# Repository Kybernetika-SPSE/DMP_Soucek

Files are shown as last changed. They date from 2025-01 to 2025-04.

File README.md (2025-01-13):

## Cíl práce
Cílem maturitní práce je navrhnout a vytvořit zařízení pro přesné měření času na závodní dráze. Součástí systému bude displej, který umožní nejen ovládání celé dráhy, ale také bude zobrazovat aktuální čas měřený během závodu. Zařízení by mělo zajistit jednoduché uživatelské rozhraní a spolehlivou funkčnost, aby bylo vhodné pro závodní podmínky.

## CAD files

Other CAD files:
Přílohy/Příloha II. - 3D Modely/Krabicka_dolni.ipt
Přílohy/Příloha II. - 3D Modely/Krabička_horni.ipt
Přílohy/Příloha II. - 3D Modely/Sestava1.iam
Přílohy/Příloha II. - 3D Modely/Tlacitko.ipt
Přílohy/Příloha II. - 3D Modely/laser_krabicka2.ipt
Přílohy/Příloha II. - 3D Modely/nožička.ipt
Přílohy/Příloha II. - 3D Modely/senzor_obal.ipt

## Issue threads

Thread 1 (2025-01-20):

Ahoj Jirko, podíváš se mi prosím na to PCB, děkuji mockrát 🙏

jakubsoucek, 2025-01-20:
odkaz: [PCB](https://github.com/Kybernetika-SPSE/DMP_Soucek/tree/3d0ee29cd1a2d0d2b6c08e4d55e5cf3c0b7b84b3/PCB)

bublinak, 2025-02-01:
Dělič napětí pro baterii 1:3 ok, ale 1M:3M? Bojím se o stabilitu a vstupní impedanci toho ESPčka. Šel bych raději max. do 100k:330k

bublinak, 2025-02-01:
Osazení si budeš dělat hádám sám..?

bublinak, 2025-02-01:
Varování: používáš vestavěný 3,3V stabilizátor na ESP. Není zrovna z nejvýkonnějších. Raději bych viděl něco externího pro ty lasery apod. A nebo - protože většina potřebuje 4,5V a více, což ti vestavěná LiPolka nedá, tak je napoj rovnou na baterii nebo na 5V a na vstup dat ze senzoru dej 1:2 dělič pro ochranu toho ESP (třeba 10k:22k). Mělo by to fungovat dobře.

bublinak, 2025-02-01:
Bacha - nemáš propojenou jednu zem. Přenastav v zóně vylité mědi izol. mezeru a tepl. mezeru na 0,25. Šířku tepl. profilu nech na 0,5
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

bublinak, 2025-02-01:
Nemáš definované vel. prokovů. Default je 0,6 s dírou 0,3. To je minimum co ti JLC vyrobí, raději bych zvětšil na 0,8:0,4 třeba. Ale mělo by to být v pohodě.

bublinak, 2025-02-01:
Zbytek OK

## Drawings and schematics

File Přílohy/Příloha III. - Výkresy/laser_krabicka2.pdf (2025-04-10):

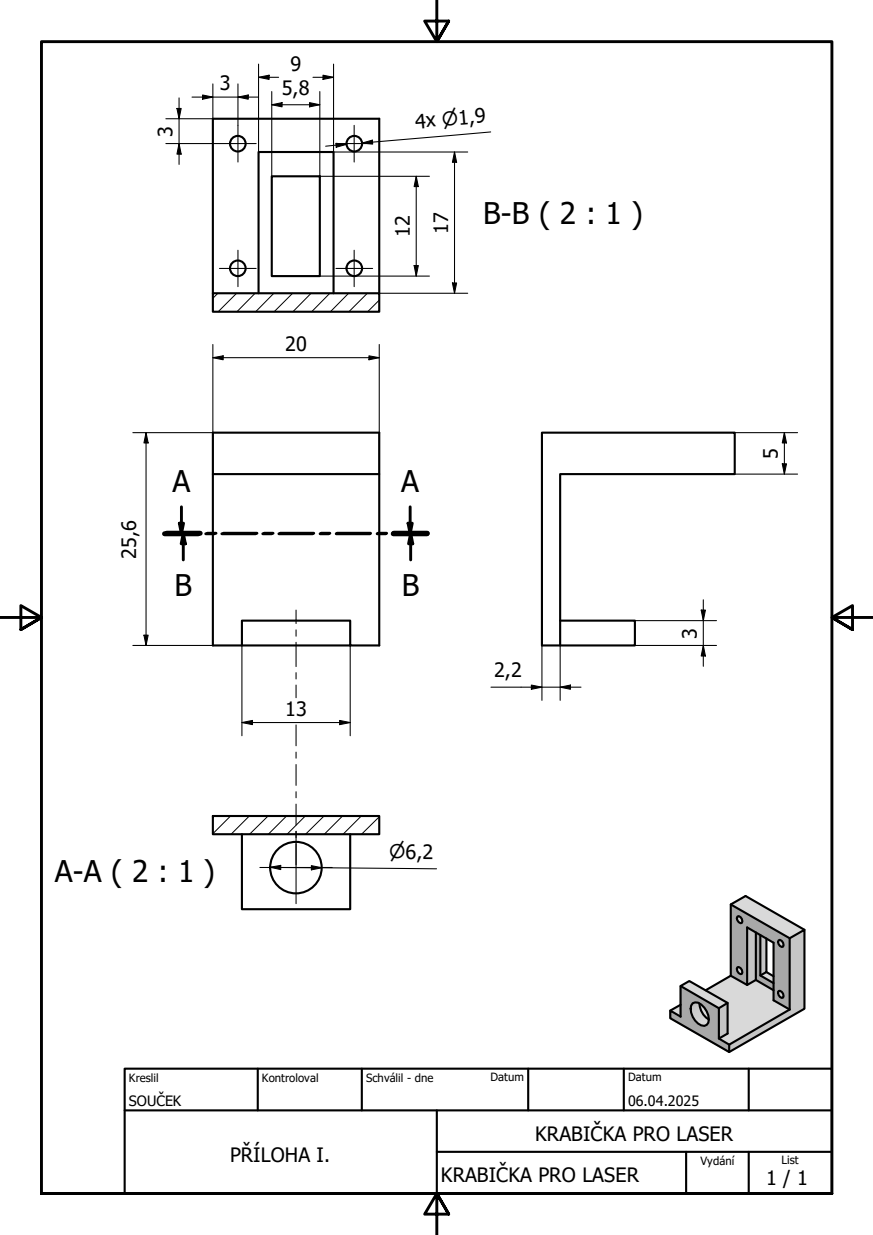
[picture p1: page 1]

Kreslil SOUČEK | Kontroloval | Schválil - dne Datum | Datum 06.04.2025

PŘÍLOHA I. | KRABIČKA PRO LASER

KRABIČKA PRO LASER | Vydání | List 1 / 1

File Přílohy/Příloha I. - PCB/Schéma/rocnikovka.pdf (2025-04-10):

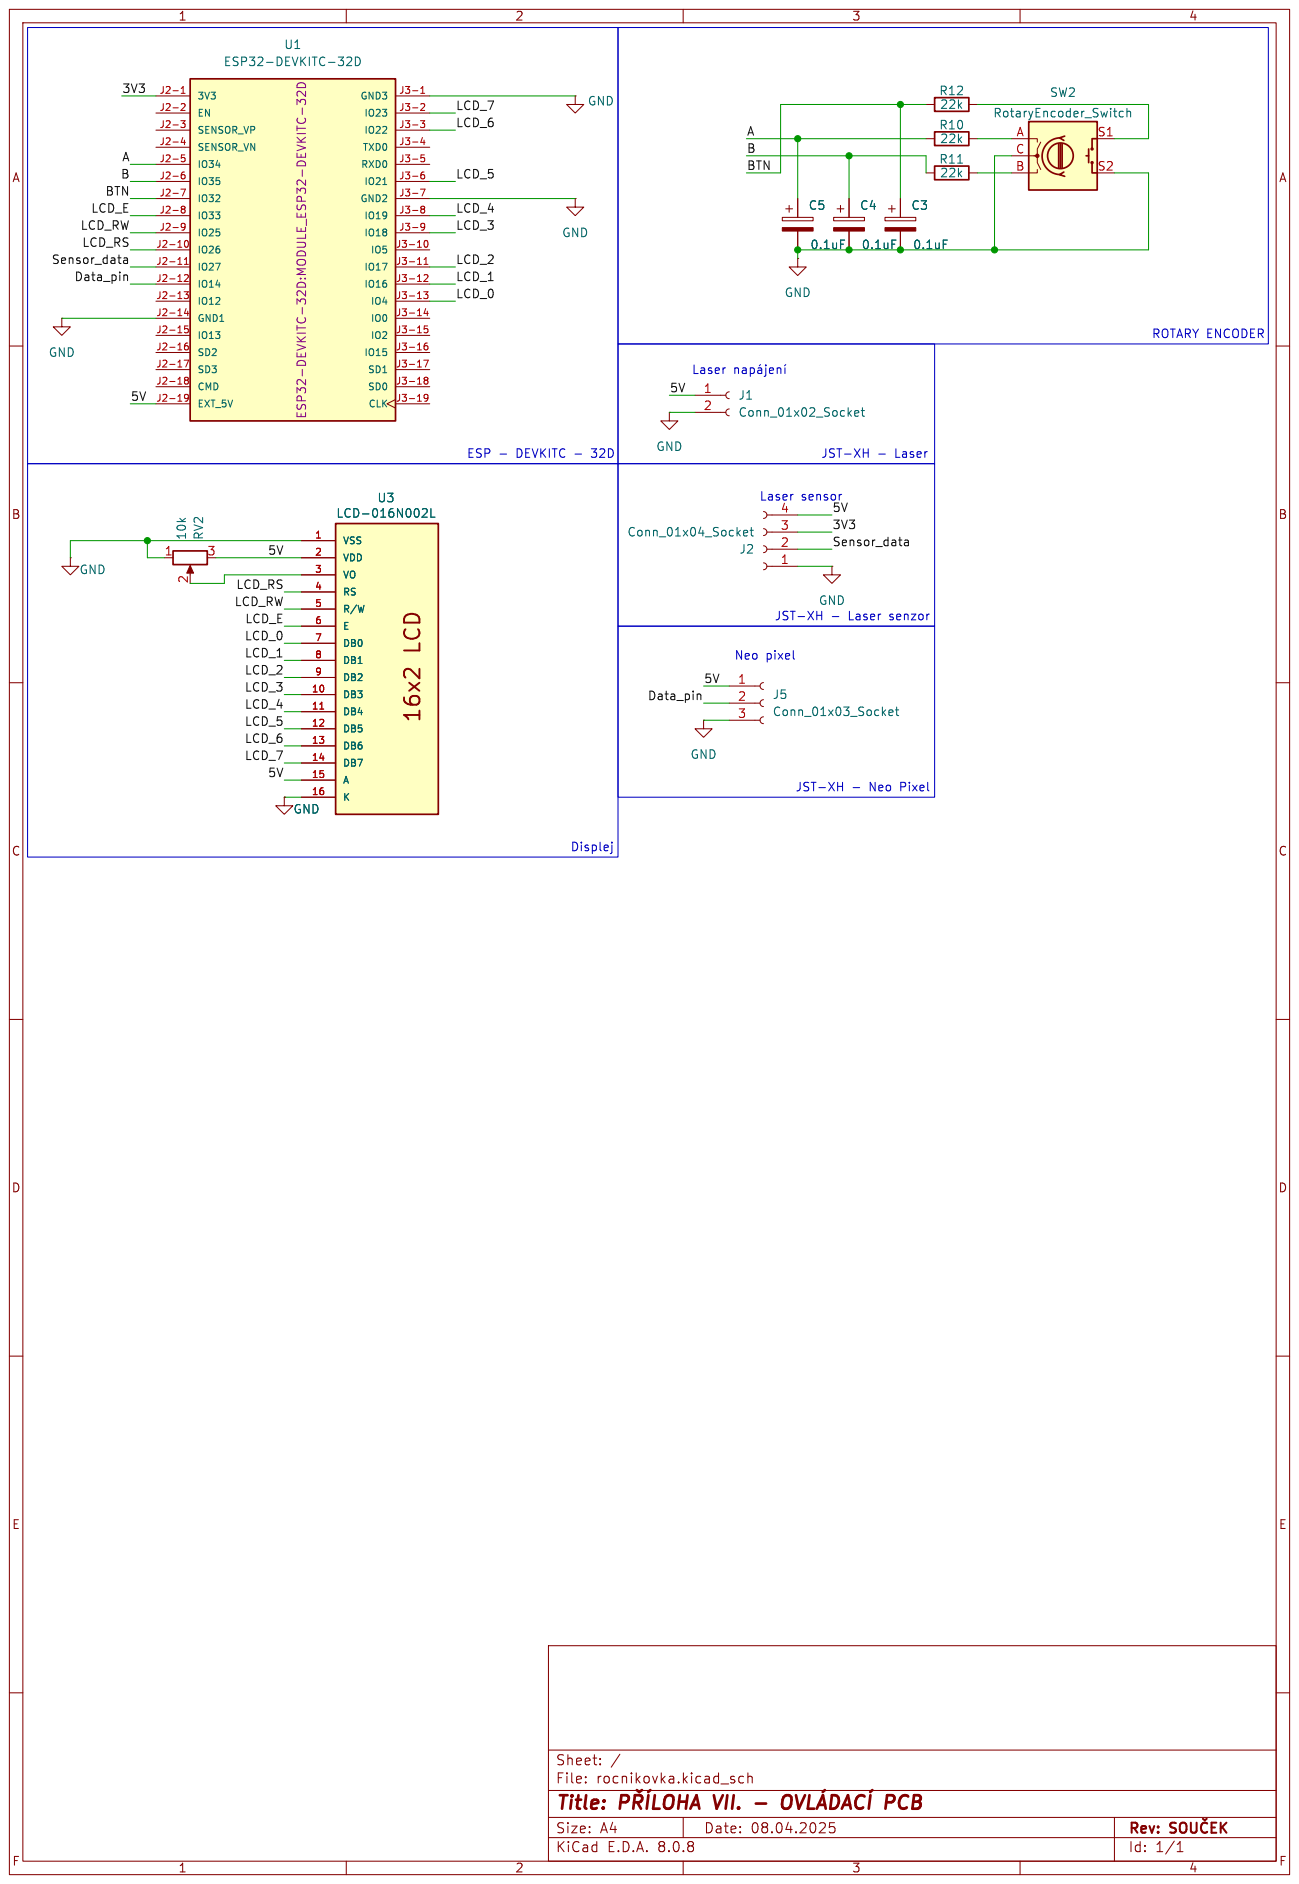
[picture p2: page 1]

Laser þÿnapájení JST-XH - Laser JST-XH - Neo Pixel C3
LCD_3

File: rocnikovka.kicad_sch Sheet: /
Id: 1/1 Title: þÿPXÍLOHA VII. - þÿOVLÁDACÍ PCB

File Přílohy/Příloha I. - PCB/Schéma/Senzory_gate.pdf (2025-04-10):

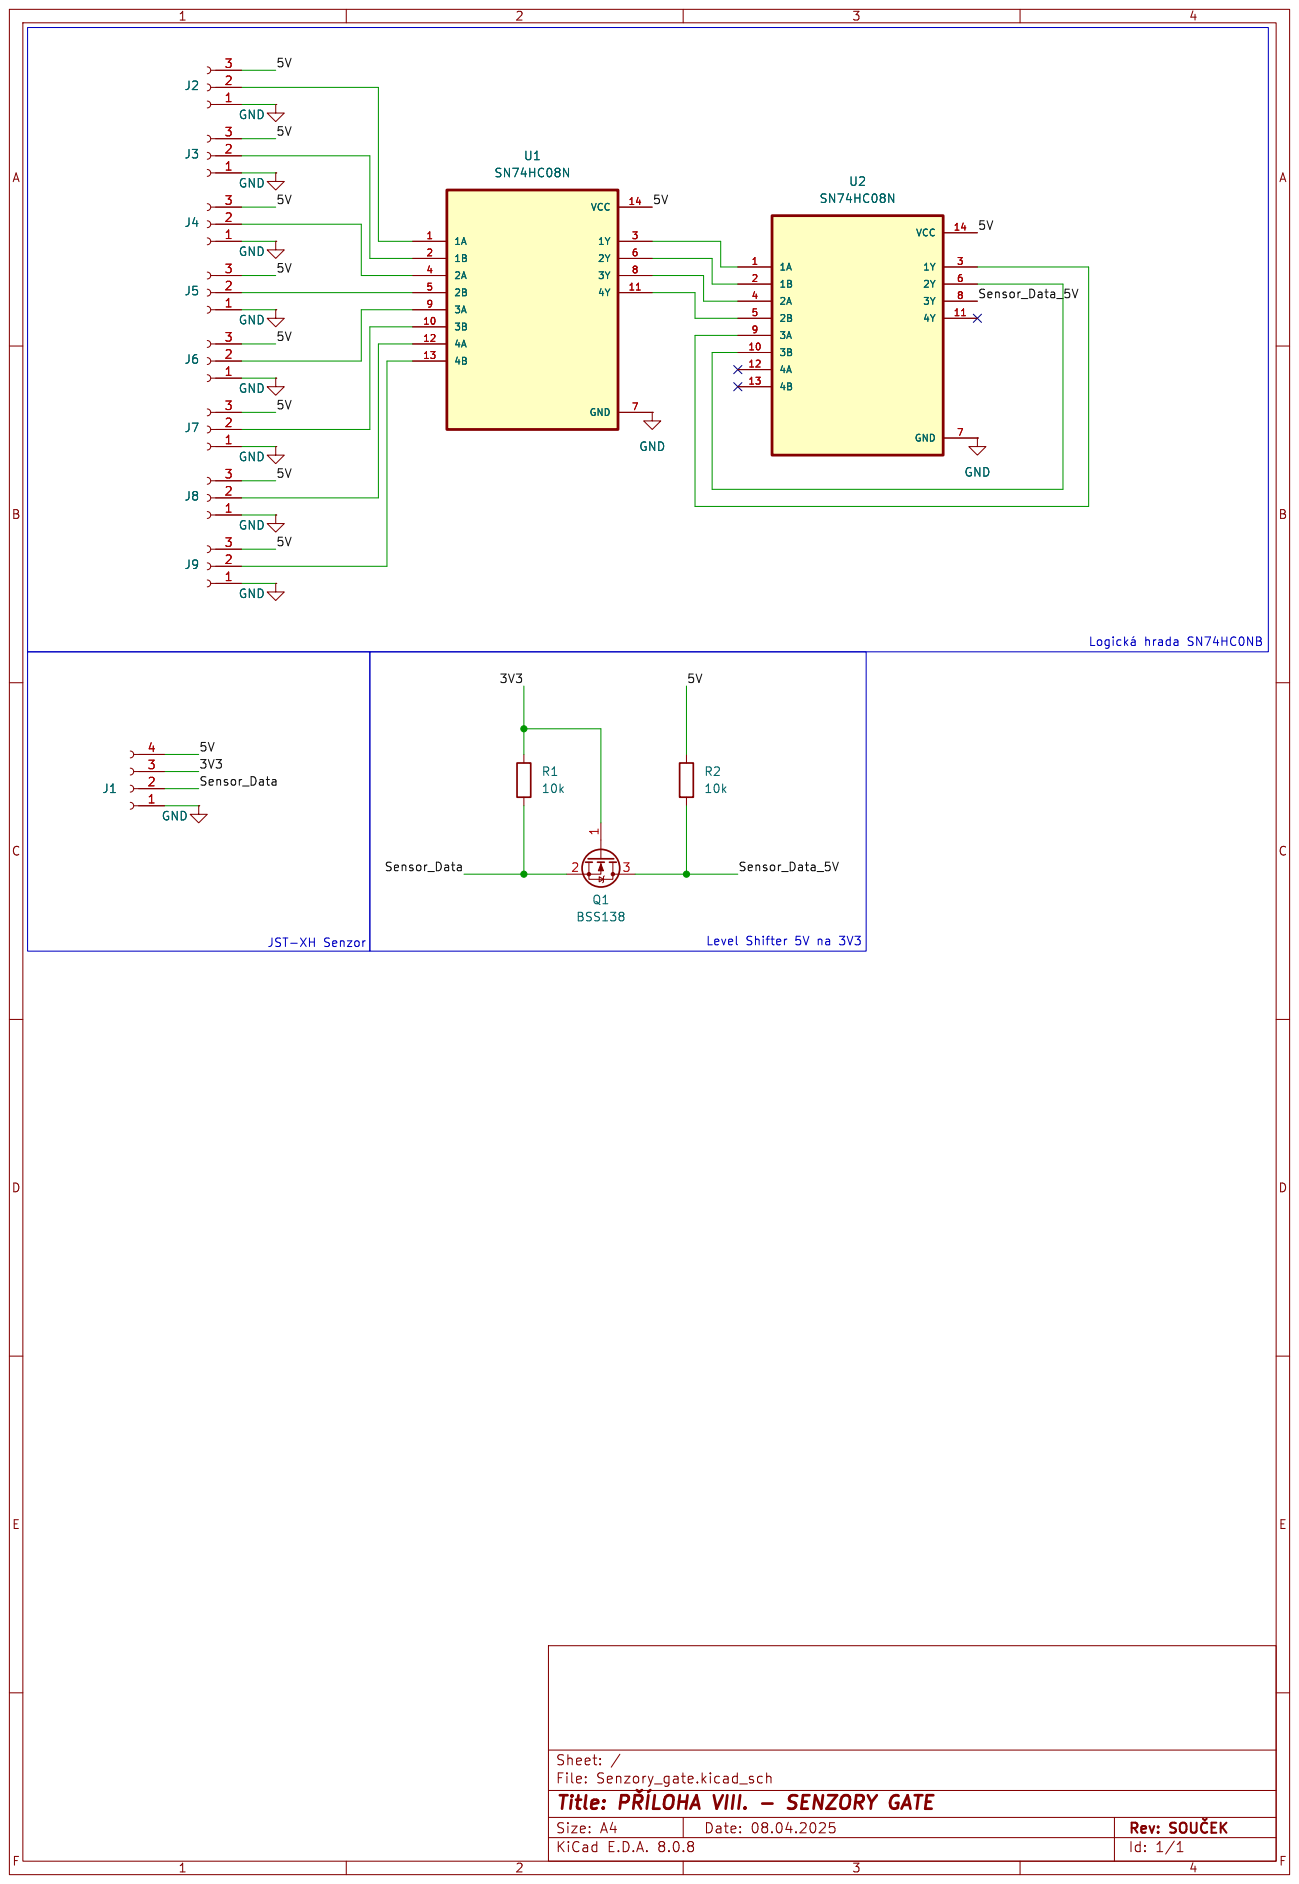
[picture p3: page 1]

File: Senzory_gate.kicad_sch Sheet: /
Id: 1/1 Title: þÿPXÍLOHA VIII. - SENZORY GATE

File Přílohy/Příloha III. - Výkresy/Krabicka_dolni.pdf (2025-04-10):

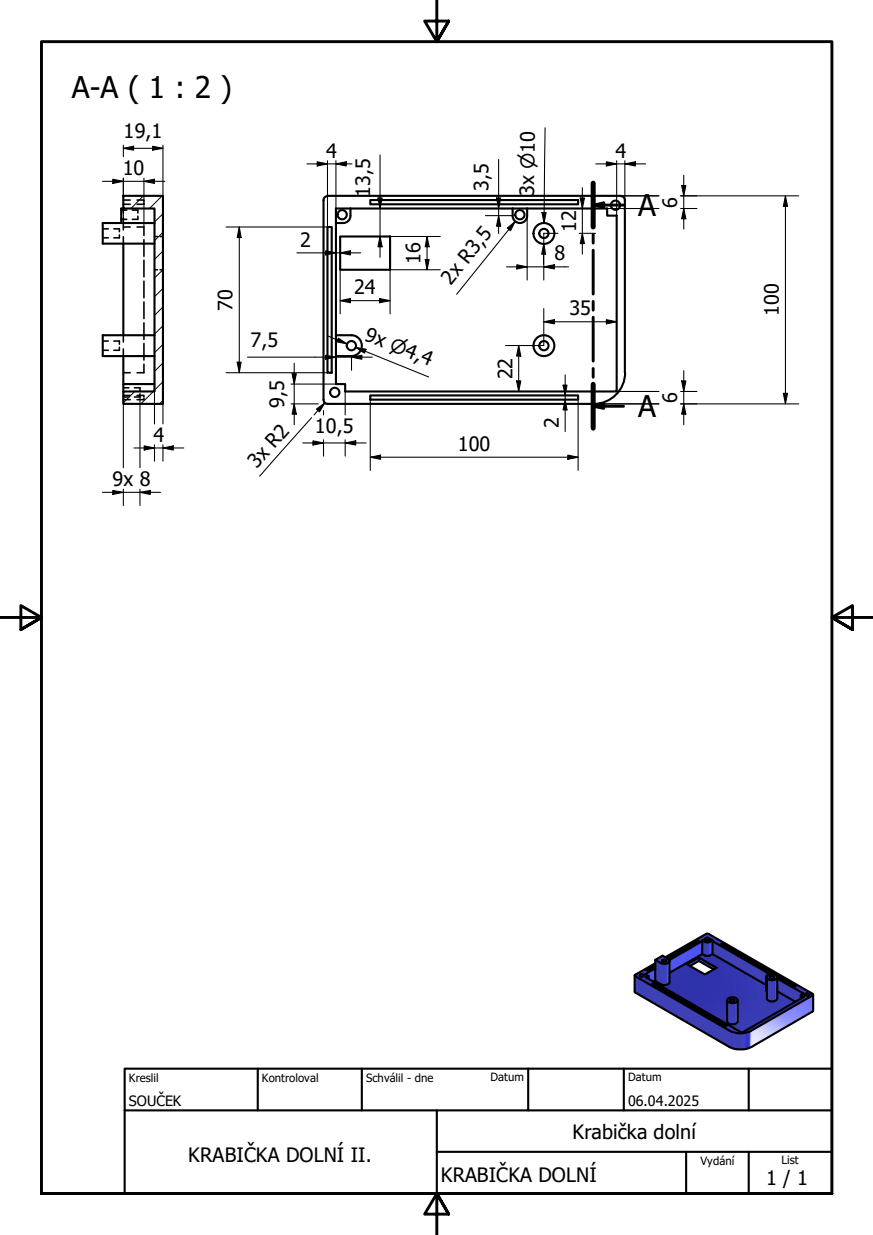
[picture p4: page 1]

Kreslil SOUČEK | Kontroloval | Schválil - dne Datum | Datum 06.04.2025

KRABIČKA DOLNÍ II. | Krabička dolní

KRABIČKA DOLNÍ | Vydání | List 1 / 1

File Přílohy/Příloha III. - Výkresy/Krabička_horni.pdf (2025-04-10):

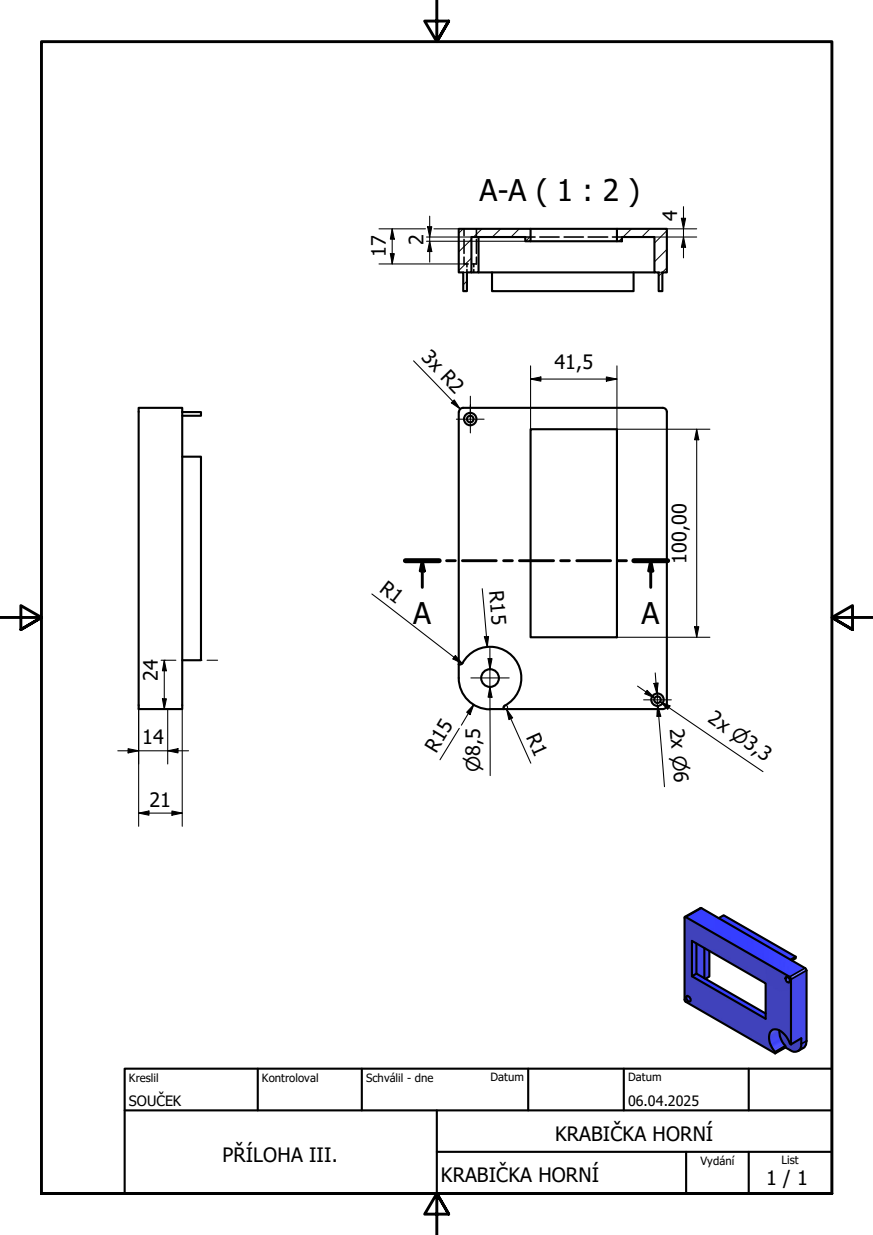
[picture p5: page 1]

Kreslil SOUČEK | Kontroloval | Schválil - dne Datum | Datum 06.04.2025

PŘÍLOHA III. | KRABIČKA HORNÍ

KRABIČKA HORNÍ | Vydání | List 1 / 1

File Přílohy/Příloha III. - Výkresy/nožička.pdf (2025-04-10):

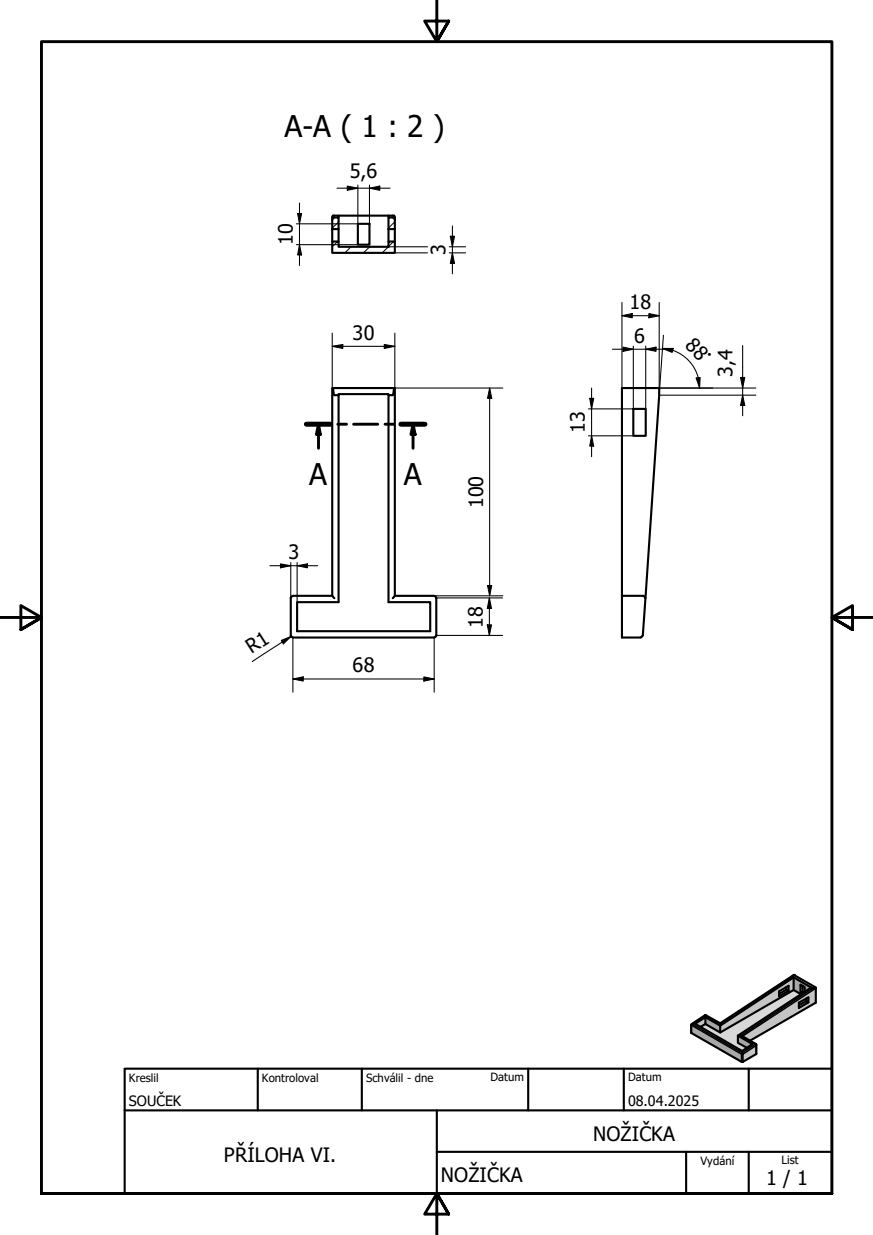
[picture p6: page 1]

Kreslil SOUČEK | Kontroloval | Schválil - dne Datum | Datum 08.04.2025

PŘÍLOHA VI. | NOŽIČKA

NOŽIČKA | Vydání | List 1 / 1

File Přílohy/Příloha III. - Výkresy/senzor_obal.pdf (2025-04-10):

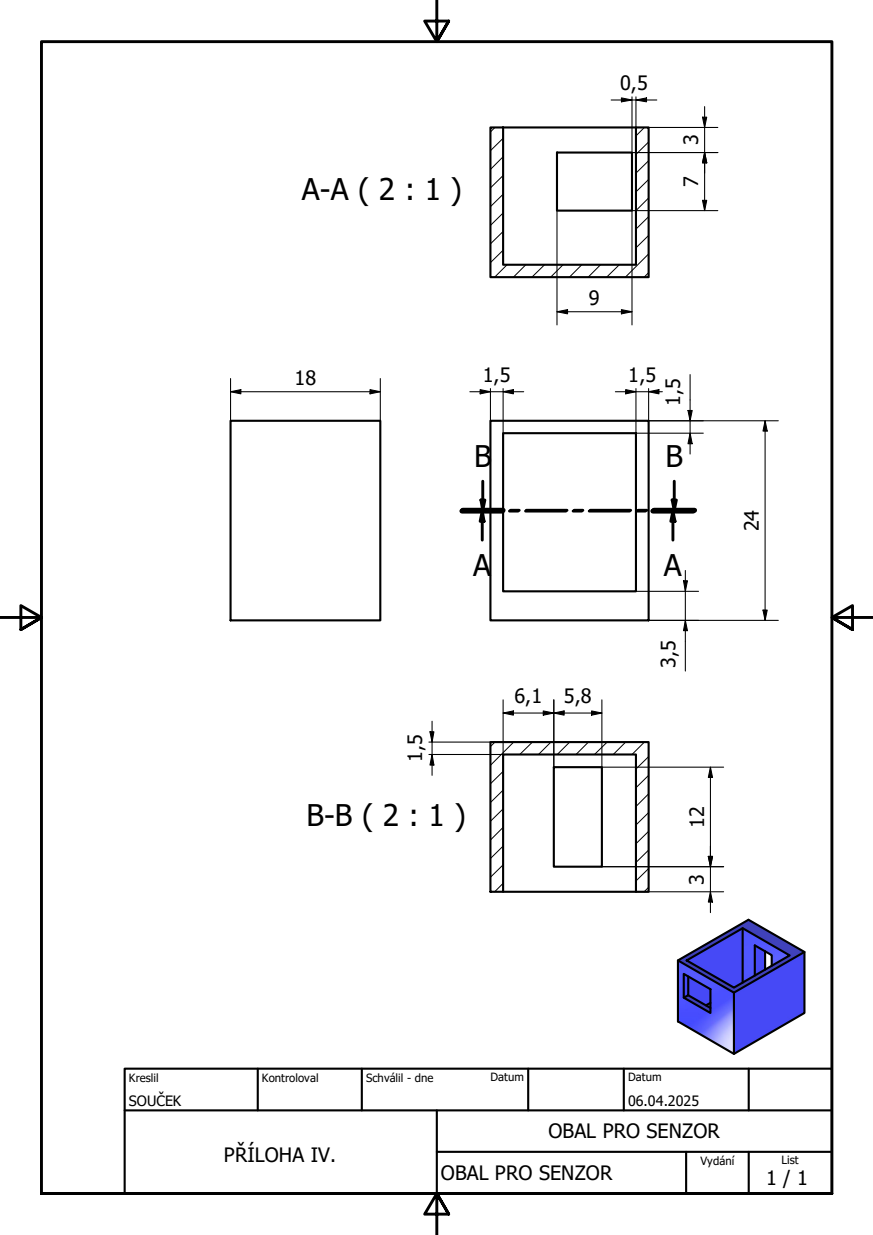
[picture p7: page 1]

Kreslil SOUČEK | Kontroloval | Schválil - dne Datum | Datum 06.04.2025

PŘÍLOHA IV. | OBAL PRO SENZOR

OBAL PRO SENZOR | Vydání | List 1 / 1

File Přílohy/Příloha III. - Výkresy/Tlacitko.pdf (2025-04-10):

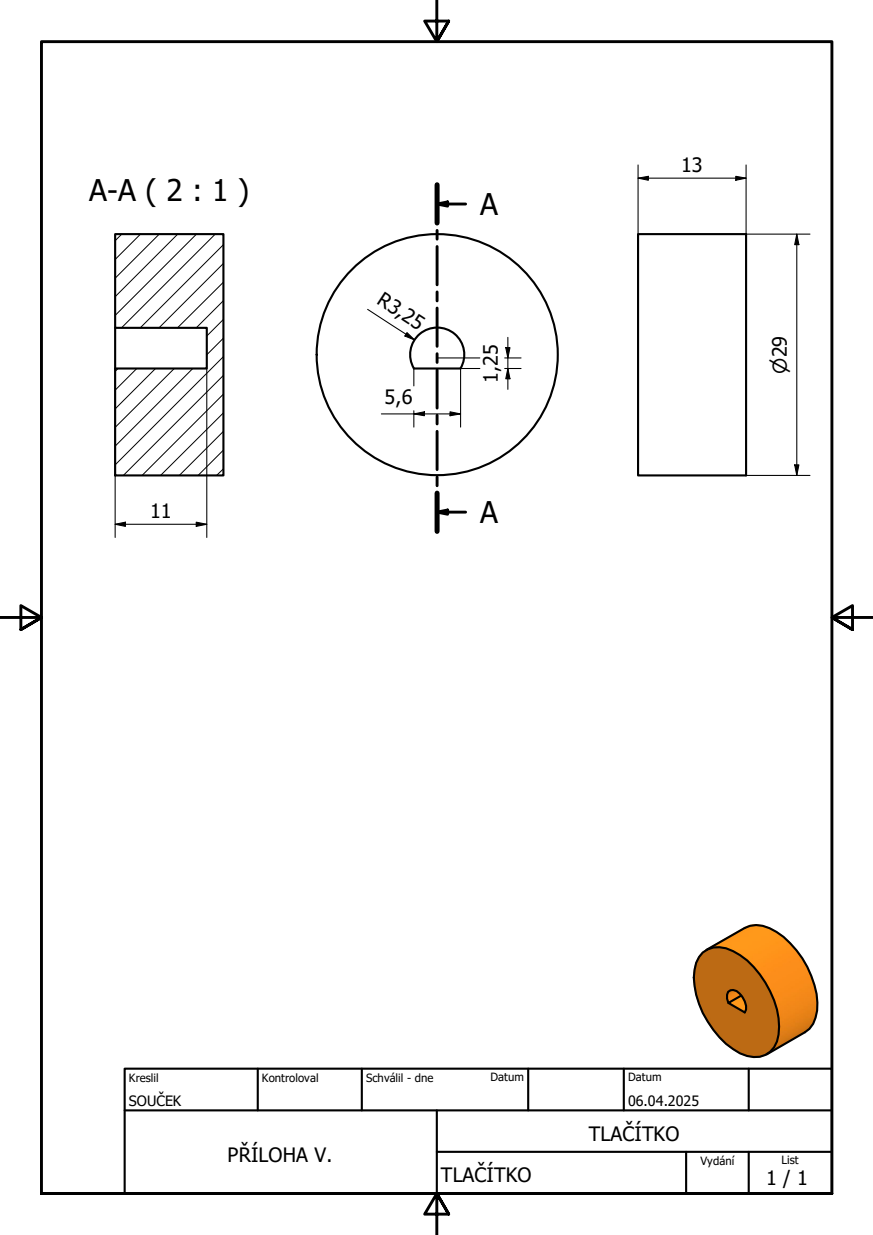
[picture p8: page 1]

Kreslil SOUČEK | Kontroloval | Schválil - dne Datum | Datum 06.04.2025

PŘÍLOHA V. | TLAČÍTKO

TLAČÍTKO | Vydání | List 1 / 1

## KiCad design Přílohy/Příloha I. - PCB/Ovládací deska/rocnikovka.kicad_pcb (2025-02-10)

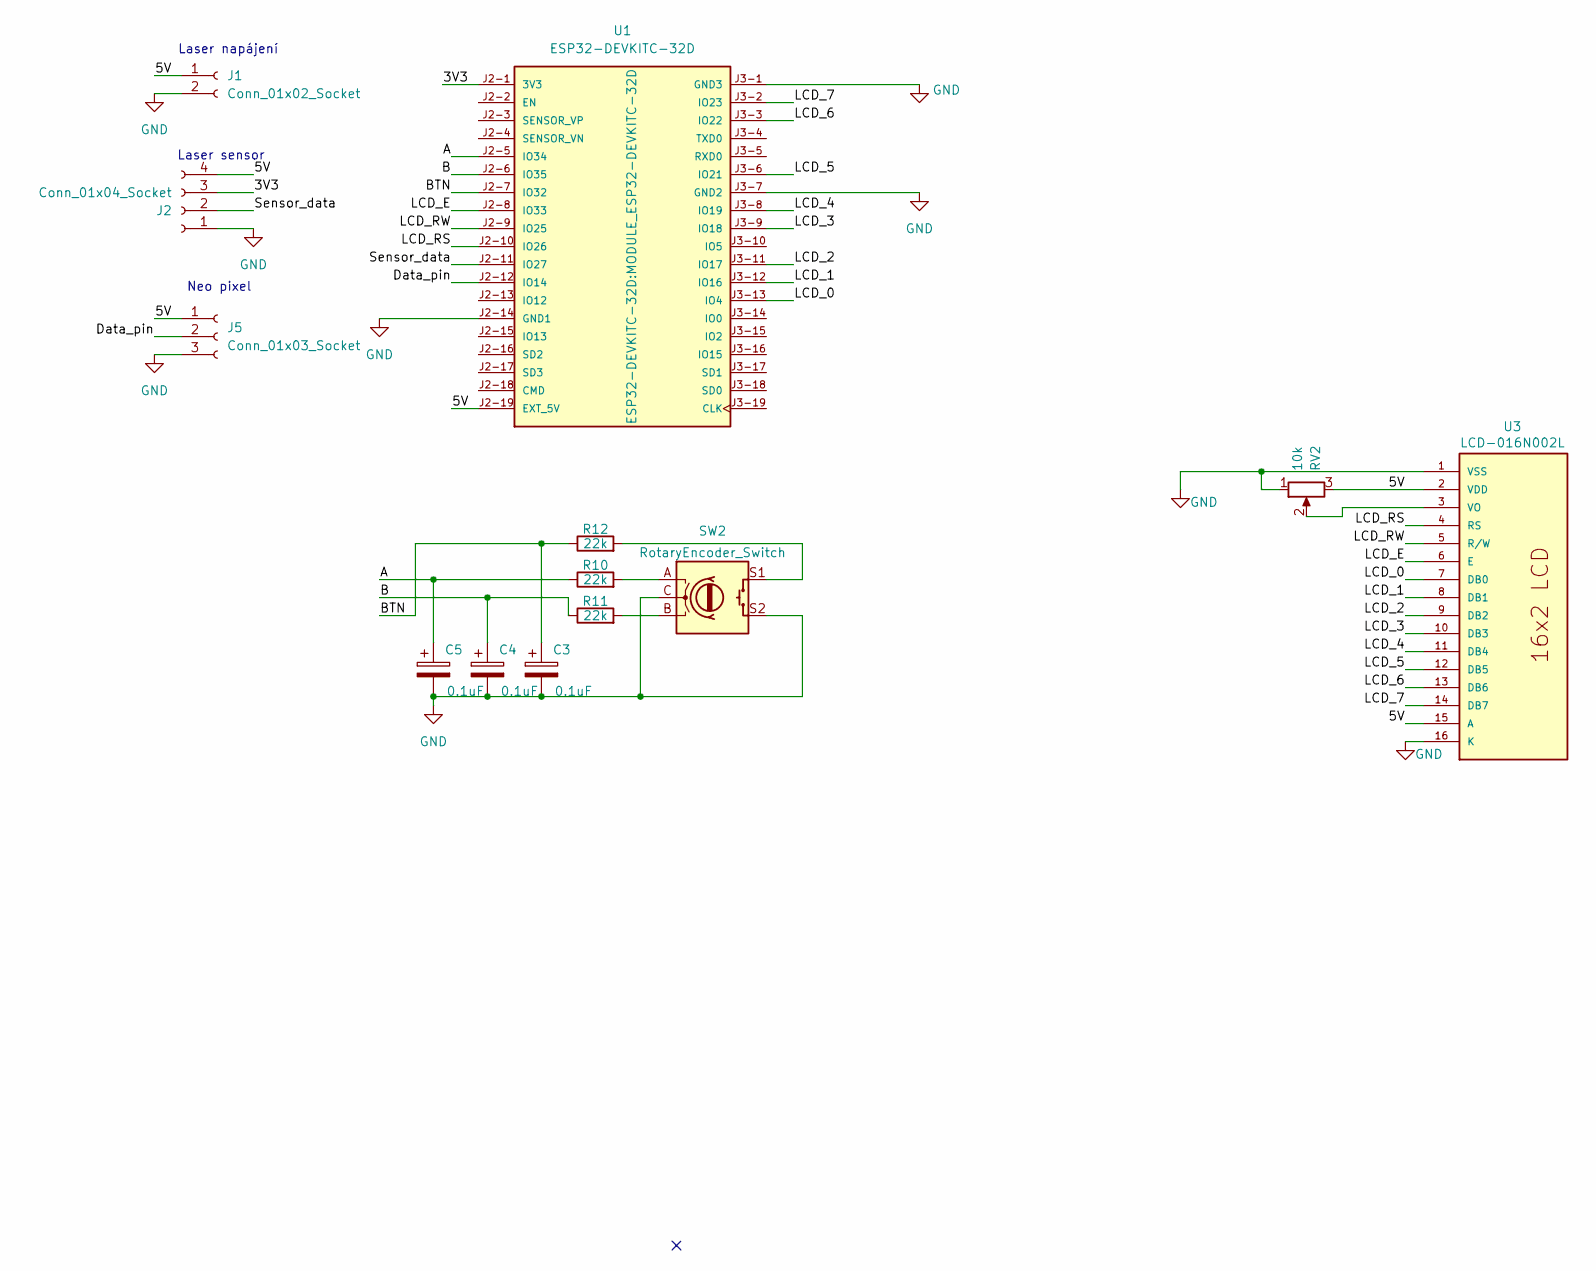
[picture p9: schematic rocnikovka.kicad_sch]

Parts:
C3, C4, C5: 0.1uF; C_0805_2012Metric_Pad1.18x1.45mm_HandSolder
J1: Conn_01x02_Socket; JST_EH_B2B-EH-A_1x02_P2.50mm_Vertical
J2: Conn_01x04_Socket; JST_EH_B4B-EH-A_1x04_P2.50mm_Vertical
J5: Conn_01x03_Socket; JST_EH_B3B-EH-A_1x03_P2.50mm_Vertical
R10, R11, R12: 22k; R_0805_2012Metric_Pad1.20x1.40mm_HandSolder
RV2: 10k; Potentiometer_ACP_CA6-VSMD_Vertical
SW2: RotaryEncoder_Switch; RotaryEncoder_Alps_EC11E-Switch_Vertical_H20mm_CircularMoun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
U1: ESP32-DEVKITC-32D; MODULE_ESP32-DEVKITC-32D; PARTREV V4
U3: LCD-016N002L; MODULE_LCD-16X2; PARTREV N/A

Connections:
/3V3: J2.3, U1.J2-1 (3V3)
/5V: J1.1, J2.4, J5.1, RV2.3, U1.J2-19 (EXT_5V), U3.2 (VDD), U3.15 (A)
/A: C5.1, R10.1, U1.J2-5 (IO34)
/B: C4.1, R11.1, U1.J2-6 (IO35)
/BTN: C3.1, R12.1, U1.J2-7 (IO32)
/Data_pin: J5.2, U1.J2-12 (IO14)
/LCD_0: U1.J3-13 (IO4), U3.7 (DB0)
/LCD_1: U1.J3-12 (IO16), U3.8 (DB1)
/LCD_2: U1.J3-11 (IO17), U3.9 (DB2)
/LCD_3: U1.J3-9 (IO18), U3.10 (DB3)
/LCD_4: U1.J3-8 (IO19), U3.11 (DB4)
/LCD_5: U1.J3-6 (IO21), U3.12 (DB5)
/LCD_6: U1.J3-3 (IO22), U3.13 (DB6)
/LCD_7: U1.J3-2 (IO23), U3.14 (DB7)
/LCD_E: U1.J2-8 (IO33), U3.6 (E)
/LCD_RS: U1.J2-10 (IO26), U3.4 (RS)
/LCD_RW: U1.J2-9 (IO25), U3.5 (R/W)
/Sensor_data: J2.2, U1.J2-11 (IO27)
GND: C3.2, C4.2, C5.2, J1.2, J2.1, J5.3, RV2.1, SW2.C, SW2.S2, U1.J2-14 (GND1), U1.J3-1 (GND3), U1.J3-7 (GND2), U3.1 (VSS), U3.16 (K)
unnamed: R10.2, SW2.A
unnamed: R11.2, SW2.B
unnamed: R12.2, SW2.S1
unnamed: RV2.2, U3.3 (VO)

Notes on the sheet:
Laser sensor
Neo pixel
Laser napájení

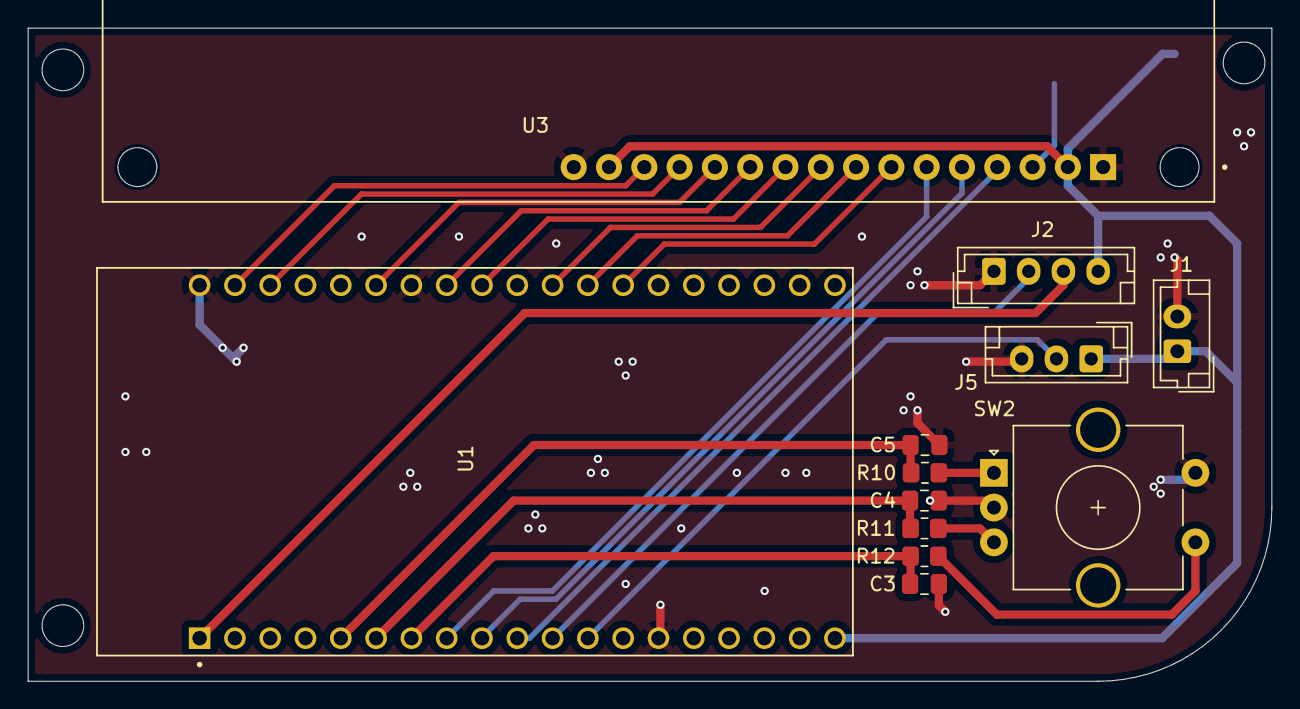
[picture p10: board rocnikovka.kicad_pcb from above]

Board: 2 copper layers, 89.5 x 47.0 mm, 13 parts (1 on the bottom side), 23 nets.

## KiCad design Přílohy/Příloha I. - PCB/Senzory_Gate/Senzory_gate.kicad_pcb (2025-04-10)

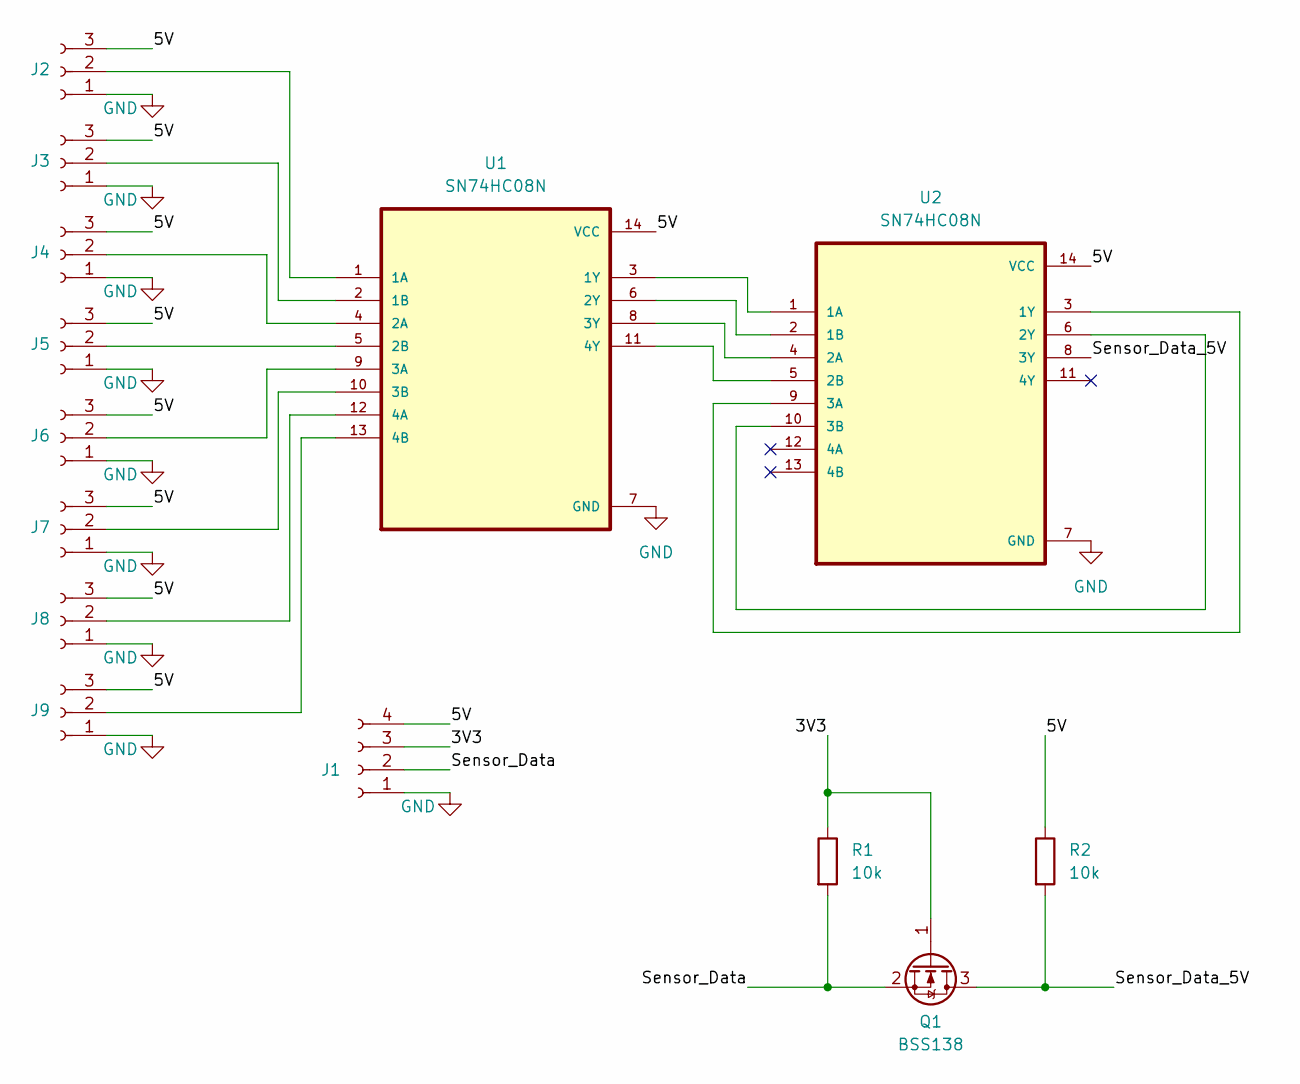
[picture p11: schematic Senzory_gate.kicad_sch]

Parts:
J1: Conn_01x04_Socket; JST_EH_B4B-EH-A_1x04_P2.50mm_Vertical
J2, J3, J4, J5, J6, J7, J8, J9: Conn_01x03_Socket; JST_EH_B3B-EH-A_1x03_P2.50mm_Vertical
Q1: BSS138; SOT-23
R1, R2: 10k; R_0603_1608Metric_Pad0.98x0.95mm_HandSolder
U1, U2: SN74HC08N; DIP794W45P254L1969H508Q14

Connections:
/3V3: J1.3, Q1.1 (G), R1.1
/5V: J1.4, J2.3, J3.3, J4.3, J5.3, J6.3, J7.3, J8.3, J9.3, R2.1, U1.14 (VCC), U2.14 (VCC)
/Sensor_Data: J1.2, Q1.2 (S), R1.2
/Sensor_Data_5V: Q1.3 (D), R2.2, U2.8 (3Y)
GND: J1.1, J2.1, J3.1, J4.1, J5.1, J6.1, J7.1, J8.1, J9.1, U1.7 (GND), U2.7 (GND)
unnamed: J2.2, U1.1 (1A)
unnamed: J3.2, U1.2 (1B)
unnamed: J4.2, U1.4 (2A)
unnamed: J5.2, U1.5 (2B)
unnamed: J6.2, U1.9 (3A)
unnamed: J7.2, U1.10 (3B)
unnamed: J8.2, U1.12 (4A)
unnamed: J9.2, U1.13 (4B)
unnamed: U1.3 (1Y), U2.1 (1A)
unnamed: U1.6 (2Y), U2.2 (1B)
unnamed: U1.8 (3Y), U2.4 (2A)
unnamed: U1.11 (4Y), U2.5 (2B)
unnamed: U2.3 (1Y), U2.9 (3A)
unnamed: U2.6 (2Y), U2.10 (3B)

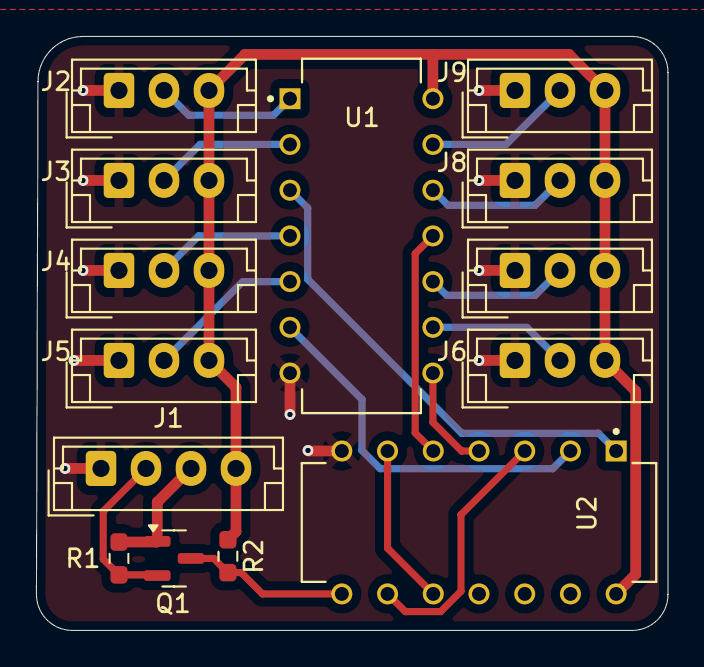
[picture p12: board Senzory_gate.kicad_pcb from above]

Board: 2 copper layers, 35.1 x 33.0 mm, 14 parts (0 on the bottom side), 19 nets.

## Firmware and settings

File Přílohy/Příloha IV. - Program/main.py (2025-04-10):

from machine import Pin 
import time
from lcd_parallel import ParallelLcd

# === LCD INIT ===
lcd = ParallelLcd(
    rs=26, en=33,
    data_pins=[4, 16, 17, 18, 19, 21, 22, 23],
    rw=25,
    cols=20, rows=4
)
lcd.clear()

# Buzzer setup (GPIO 15)
buzzer = Pin(15, Pin.OUT)

# Rotary encoder setup
dt_pin = Pin(35, Pin.IN)
clk_pin = Pin(34, Pin.IN)
sw_pin = Pin(32, Pin.IN, Pin.PULL_UP)
last_clk = clk_pin.value()
click_count = 0

# Laser gate input
gate_pin = Pin(27, Pin.IN)

# Globals
menu_items = ["Start Race", "View Results", "Reset Timer", "Settings", "Exit"]
menu_index = 0
menu_page = 0
race_active = False
last_gate_state = gate_pin.value()
lap_times = []
start_time = None
best_lap = None
lap_goal = 3
race_mode = "Lap"
time_trial_duration = 60

def splash_screen():
    lcd.clear()
    lcd.set_cursor(2, 1)
    lcd.putstr("FPV DRONE GATE")
    lcd.set_cursor(1, 2)
    lcd.putstr("Click to Start...")
    while sw_pin.value() == 1:
        time.sleep(0.01)
    time.sleep(0.3)
    lcd.clear()

def show_menu():
    lcd.clear()
    start = menu_page * 4
    end = min(start + 4, len(menu_items))
    for i in range(start, end):
        prefix = ">" if i == menu_index else " "
        lcd.set_cursor(0, i - start)
        lcd.putstr("{} {}".format(prefix, menu_items[i]))

def reset_timer():
    global lap_times, best_lap, start_time
    lap_times = []
    best_lap = None
    start_time = None

# === START ===
splash_screen()
show_menu()

while True:
    clk_state = clk_pin.value()
    if clk_state != last_clk:
        if clk_state == 0:
            if dt_pin.value() != clk_state:
                click_count += 1
            else:
                click_count -= 1
            if click_count >= 1:
                menu_index = (menu_index + 1) % len(menu_items)
                click_count = 0
            elif click_count <= -1:
                menu_index = (menu_index - 1) % len(menu_items)
                click_count = 0
            menu_page = menu_index // 4
            show_menu()
        last_clk = clk_state

    if sw_pin.value() == 0:
        selected_item = menu_items[menu_index]
        lcd.clear()
        lcd.set_cursor(0, 1)
        lcd.putstr("Selected: {}".format(selected_item))
        time.sleep(0.8)

        # === START RACE ===
        if selected_item == "Start Race":
            for i in range(10, 0, -1):
                lcd.clear()
                lcd.set_cursor(2, 1)
                lcd.putstr("Starting in {}...".format(i))
                time.sleep(1)
            lcd.clear()
            lcd.set_cursor(4, 1)
            lcd.putstr("GO!")
            time.sleep(1)
            lcd.clear()

            reset_timer()
            race_active = True
            lap = 0
            last_gate_state = gate_pin.value()
            start_time = time.ticks_ms()

            if race_mode == "Lap":
                while race_active:
                    now = time.ticks_ms()
                    elapsed = time.ticks_diff(now, start_time) / 1000
                    lcd.set_cursor(0, 0)
                    lcd.putstr("Lap: {}/{}      ".format(lap, lap_goal))
                    lcd.set_cursor(0, 1)
                    lcd.putstr("Time: {:.2f}s    ".format(elapsed))

                    current_gate = gate_pin.value()
                    if last_gate_state == 1 and current_gate == 0:
                        buzzer.value(1)
                        time.sleep(0.2)
                        buzzer.value(0)
                        
                        lap_time = elapsed
                        lap += 1
                        lap_times.append(lap_time)
                        start_time = now
                        if best_lap is None or lap_time < best_lap:
                            best_lap = lap_time
                        lcd.clear()
                        lcd.set_cursor(0, 0)
                        lcd.putstr("Lap {}: {:.2f}s".format(lap, lap_time))
                        lcd.set_cursor(0, 1)
                        lcd.putstr("Best: {:.2f}s".format(best_lap))
                        time.sleep(2)
                        if lap >= lap_goal:
                            lcd.clear()
                            lcd.putstr("Race Complete!")
                            time.sleep(2)
                            race_active = False
                            break
                    last_gate_state = current_gate
                    time.sleep(0.05)

            elif race_mode == "Time":
                time_limit_ms = time_trial_duration * 1000
                while race_active:
                    now = time.ticks_ms()
                    elapsed = time.ticks_diff(now, start_time)
                    remaining = max(0, time_limit_ms - elapsed)
                    lcd.set_cursor(0, 0)
                    lcd.putstr("Time Left: {:>4}s".format(int(remaining / 1000)))
                    lcd.set_cursor(0, 1)
                    lcd.putstr("Laps: {}".format(lap))

                    if remaining <= 0:
                        lcd.clear()
                        lcd.set_cursor(0, 0)
                        lcd.putstr("Time's up!")
                        lcd.set_cursor(0, 1)
                        lcd.putstr("Laps: {}".format(lap))
                        time.sleep(3)
                        race_active = False
                        break

                    current_gate = gate_pin.value()
                    if last_gate_state == 1 and current_gate == 0:
                        buzzer.value(1)
                        time.sleep(0.2)
                        buzzer.value(0)
                        
                        lap += 1
                        lap_time = time.ticks_diff(now, start_time) / 1000
                        lap_times.append(lap_time)
                        lcd.set_cursor(0, 2)
                        lcd.putstr("Lap {}: {:.2f}s".format(lap, lap_time))
                        time.sleep(1.5)
                        lcd.set_cursor(0, 2)
                        lcd.putstr(" " * 20)
                    last_gate_state = current_gate
                    time.sleep(0.05)

            show_menu()
        # === VIEW RESULTS ===
        elif selected_item == "View Results":
            lcd.clear()
            if lap_times:
                total_time = sum(lap_times)
                index = 0
                total = len(lap_times)
                while True:
                    lcd.clear()
                    lcd.set_cursor(0, 0)
                    lcd.putstr("Total: {:.3f}s".format(total_time))
                    for i in range(1, 4):
                        if index + i - 1 < total:
                            lap = lap_times[index + i - 1]
                            lcd.set_cursor(0, i)
                            lcd.putstr("{}. {:.3f}s".format(index + i, lap))
                        else:
                            lcd.set_cursor(0, i)
                            lcd.putstr(" " * 20)
                    if index + 3 >= total:
                        lcd.set_cursor(0, 3)
                        lcd.putstr("> Back to Menu")

                    wait_release = True
                    back_pressed = False
                    while True:
                        clk_state = clk_pin.value()
                        if clk_state != last_clk:
                            if clk_state == 0:
                                if dt_pin.value() != clk_state:
                                    index += 3
                                    if index >= total:
                                        index = 0
                                    break
                            last_clk = clk_state

                        if sw_pin.value() == 0 and wait_release:
                            wait_release = False
                        elif sw_pin.value() == 1 and not wait_release:
                            if index + 3 >= total:
                                back_pressed = True
                                break
                        time.sleep(0.01)

                    if back_pressed:
                        break
                show_menu()
            else:
                lcd.clear()
                lcd.putstr("No Results Yet.")
                time.sleep(2)
                show_menu()

        # === RESET TIMER ===
        elif selected_item == "Reset Timer":
            reset_timer()
            lcd.clear()
            lcd.putstr("Timer Reset.")
            time.sleep(1.5)
            show_menu()

        # === SETTINGS ===
        elif selected_item == "Settings":
            settings_menu = ["Lap Race", "Time Trial", "Back to Menu"]
            settings_index = 0
            selecting = True
            while selecting:
                lcd.clear()
                lcd.set_cursor(0, 0)
                lcd.putstr("Race Format")
                for i, item in enumerate(settings_menu):
                    prefix = ">" if i == settings_index else " "
                    lcd.set_cursor(0, i + 1)
                    lcd.putstr("{} {}".format(prefix, item))
                time.sleep(0.15)

                clk_state = clk_pin.value()
                if clk_state != last_clk:
                    if clk_state == 0:
                        if dt_pin.value() != clk_state:
                            click_count += 1
                        else:
                            click_count -= 1
                        if click_count >= 1:
                            settings_index = (settings_index + 1) % len(settings_menu)
                            click_count = 0
                        elif click_count <= -1:
                            settings_index = (settings_index - 1) % len(settings_menu)
                            click_count = 0
                    last_clk = clk_state

                if sw_pin.value() == 0:
                    time.sleep(0.3)
                    if settings_menu[settings_index] == "Lap Race":
                        race_mode = "Lap"
                        lap_index = 0
                        while True:
                            lcd.clear()
                            lcd.set_cursor(0, 0)
                            lcd.putstr("Set Laps: {}".format(lap_goal))
                            lcd.set_cursor(0, 1)
                            lcd.putstr("> Back to Menu" if lap_index == 1 else "  Back to Menu")
                            time.sleep(0.15)

                            clk_state = clk_pin.value()
                            if clk_state != last_clk:
                                if clk_state == 0:
                                    if dt_pin.value() != clk_state:
                                        click_count += 1
                                    else:
                                        click_count -= 1
                                    if click_count >= 1:
                                        lap_index = (lap_index + 1) % 2
                                        click_count = 0
                                    elif click_count <= -1:
                                        lap_index = (lap_index - 1) % 2
                                        click_count = 0
                                last_clk = clk_state

                            if sw_pin.value() == 0:
                                if lap_index == 0:
                                    lap_goal += 1
                                    if lap_goal > 10:
                                        lap_goal = 1
                                else:
                                    break
                                time.sleep(0.3)

                    elif settings_menu[settings_index] == "Time Trial":
                        race_mode = "Time"
                        time_index = 0
                        while True:
                            lcd.clear()
                            lcd.set_cursor(0, 0)
                            lcd.putstr("Set Time: {}s".format(time_trial_duration))
                            lcd.set_cursor(0, 1)
                            lcd.putstr("> Back to Menu" if time_index == 1 else "  Back to Menu")
                            time.sleep(0.15)

                            clk_state = clk_pin.value()
                            if clk_state != last_clk:
                                if clk_state == 0:
                                    if dt_pin.value() != clk_state:
                                        click_count += 1
                                    else:
                                        click_count -= 1
                                    if click_count >= 1:
                                        time_index = (time_index + 1) % 2
                                        click_count = 0
                                    elif click_count <= -1:
                                        time_index = (time_index - 1) % 2
                                        click_count = 0
                                last_clk = clk_state

                            if sw_pin.value() == 0:
                                if time_index == 0:
                                    time_trial_duration += 30
                                    if time_trial_duration > 150:
                                        time_trial_duration = 30
                                else:
                                    break
                                time.sleep(0.3)

                    elif settings_menu[settings_index] == "Back to Menu":
                        selecting = False
            show_menu()

        # === EXIT ===
        elif selected_item == "Exit":
            splash_screen()
            show_menu()

    time.sleep(0.01)

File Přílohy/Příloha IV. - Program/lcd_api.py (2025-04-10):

# lcd_api.py

class LcdApi:
    """Base LCD API with correct 20x4 row mapping."""

    LCD_CLR = 0x01
    LCD_HOME = 0x02
    LCD_ENTRY_MODE = 0x04
    LCD_ON_CTRL = 0x08
    LCD_MOVE = 0x10
    LCD_FUNCTION = 0x20
    LCD_CGRAM = 0x40
    LCD_DDRAM = 0x80

    ENTRY_LEFT = 0x02
    ENTRY_SHIFT = 0x01

    ON_DISPLAY = 0x04
    ON_CURSOR = 0x02
    ON_BLINK = 0x01

    MOVE_DISP = 0x08
    MOVE_RIGHT = 0x04
    MOVE_LEFT = 0x00

    FUNCTION_8BIT = 0x10
    FUNCTION_2LINES = 0x08
    FUNCTION_5X10 = 0x04

    def __init__(self, num_lines, num_cols):
        self.num_lines = num_lines
        self.num_cols = num_cols

        self.init_lcd()

    def init_lcd(self):
        self.write_command(self.LCD_FUNCTION | self.FUNCTION_8BIT | self.FUNCTION_2LINES)
        self.write_command(self.LCD_ON_CTRL | self.ON_DISPLAY)
        self.write_command(self.LCD_ENTRY_MODE | self.ENTRY_LEFT)
        self.clear()

    def clear(self):
        self.write_command(self.LCD_CLR)
        self.delay_ms(2)

    def home(self):
        self.write_command(self.LCD_HOME)
        self.delay_ms(2)

    def set_cursor(self, col, row):
        # Proper row offsets for 20x4 LCD
        row_offsets = [0x00, 0x40, 0x14, 0x54]
        if row >= self.num_lines:
            row = self.num_lines - 1
        addr = self.LCD_DDRAM | (col + row_offsets[row])
        self.write_command(addr)



    def putstr(self, string):
        for char in string:
            self.write_data(ord(char))

    # Abstract methods to be implemented in subclass
    def write_command(self, cmd):
        raise NotImplementedError

    def write_data(self, data):
        raise NotImplementedError

    def delay_ms(self, ms):
        from time import sleep_ms
        sleep_ms(ms)

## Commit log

2024-10-30 Rename Pokrok v maturitní práci 1.pdf to Pokrok_DMP_rijen.pdf
2025-01-13 Rename Pokrok v maturitní práci 2.pdf to Pokrok v maturitní práci - prosinec.pdf
2025-01-13 Rename Pokrok v maturitní práci - prosinec.pdf to Pokrok_DMP_prosinec.pdf
2025-01-14 Create PCB
2025-01-20 Přidání PCB
    [rocnikovka.kicad_pcb, rocnikovka.kicad_sch]
2025-04-10 Náhraní všecho
    blablabla
    [Krabicka_dolni.ipt, Krabička_horni.ipt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]
